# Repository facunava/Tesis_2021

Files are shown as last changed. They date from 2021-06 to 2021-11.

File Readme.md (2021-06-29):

# Tesis de grado. Grupo 6/2021
Este repositorio esta destinado al desarrollo de la tesis para obtener el grado de Ingeniero Electrónico en la Universidad Tecnológica Nacional Facultad regional de Córdoba.

---

## Problemática a resolver.
En la zona rural del Valle de Calamuchita (Córdoba, Argentina) se encuentra un emprendimiento cordobés "Azafrán Mediterráneo" dedicado a la cosecha, producción e inversión en "Crocus Sativus" (Azafrán), de esta planta violácea se utilizan los pistilos para la producción de la preciada especia, la cual se utiliza en una amplia variedad de rubros, ademas del azafrán de mesa, lo podemos encontrar como materia prima en linea estética para champú, perfumes, colonias, e incluso se utiliza en la producción de fernet.

<p align="center">
	Crocus Sativus 
</p>

Su alto valor comercial reside en la forma artesanal de su cosecha, de la misma manera que se hacia hace centenares de años, se sigue haciendo de forma manual, "Azafrán Mediterráneo" cuenta con "piletones" de material los cuales le permiten un mejor control de las variables que favorecen el crecimiento de los bulbos, como riego, fertilización y calidad del sustrato.

<p align="center">
	Piletones para cosecha 
</p>

Esta planta es azotada por una clase de hongo que crece en determinadas condiciones de temperatura y humedad, el objetivo de este proyecto es monitoriar dichas variables del suelo para poder activar unas electroválvulas del sistema de riego por goteo cambiando los valores que favorecen la proliferación del hongo.

Esto va a estar controlado a través de un servidor hosteado de forma local en una Raspberry Pi, en conjunto con una placa a modo de "HAT" que contenga un microcontrolador (ESP32) encargado de la adquisición de las lecturas de los sensores y activación de los actuadores.

---

## Integrantes

- Castro, Franco
- Cussa, Mayco
- Navarro, Facundo
- Nobile, Jonathan

---

### TODO
* Hardware
	+ Iniciar PCB

* Software
	+ Configurar Home Assistant
	+ Mejorar firmware ESP32

---

> Al fin y al cabo, somos lo que hacemos para cambiar lo que somos.
> - Eduadro Galeano.

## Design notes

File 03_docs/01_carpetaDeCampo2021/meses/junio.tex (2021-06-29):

\section{Junio 2021}

\subsection*{Martes 01/06/21}
    \begin{itemize}
        \item MQTT ESP32 y Raspberry Pi 3B+ en script "Python"
            \begin{itemize}
                 \item \href{https://www.instructables.com/How-to-Use-MQTT-With-the-Raspberry-Pi-and-ESP8266/}{Tutorial MQTT ESP8266 + Raspberry pi}
            \end{itemize}
\end{itemize}

\subsection*{Miércoles 02/06/21}
\begin{itemize}
    \item Prueba de servidor publico, web server nginx, DDNS publico de \href{https://www.noip.com/}{\textbf{No-IP}}, se abrieron los puertos del router 80 y se asigno una ip fija (192.168.1.100) a la RPi. 
    \begin{itemize}
        \item \href{http://facunava.ddns.net}{Pagina de prueba}
    \end{itemize}
    \item Se buscan materiales necesarios para calibración de sensores.
\end{itemize}    
\subsection*{Jueves 03/06/21}
    \begin{itemize}
        \item Prueba de framework Flask, en conjunto con el Web Server Nginx, y como herramienta de deployment Gunicorn, ya que por si solo flask sirve para ejecutar de forma local y no está orientado a usuarios multilples.
        \begin{itemize}
            \item \href{https://linuxhint.com/use-nginx-with-flask/}{Nginx + Flask + Gunicorn}
            \item \href{https://j2logo.com/tutorial-flask-leccion-17-desplegar-flask-produccion-nginx-gunicorn/}{Nginx + Flask + Gunicorn}
            \item \href{https://faun.pub/deploy-flask-app-with-nginx-using-gunicorn-7fda4f50066a}{Nginx + Flask + Gunicorn}
        \end{itemize}
        
        \item Prueba de comunicacion MQTT desde la ESP a la Rpi3 e intentamos presentar esa información a través de flask a una pagina web local en html.
        \begin{itemize}
            \item \href{https://www.rosietheredrobot.com/2018/11/red-current-and-serial.html}{MQTT + Esp32 + Http + WebSockets}
            \item \href{https://www.rosietheredrobot.com/2017/09/a-web-of-pies.html}{Instalación de Flask}
        \end{itemize}
    \end{itemize}
\subsection*{Viernes 04/06/21}
    \begin{itemize}
        \item Dia Libre.
    \end{itemize}

\subsection*{Sábado 05/06/21}
    \begin{itemize}
        \item Dia Libre.
    \end{itemize}

\subsection*{Domingo 06/06/21}
    \begin{itemize}
        \item Dia Libre.
    \end{itemize}
\subsection*{Lunes 07/06/21}
    \begin{itemize}
        \item Pruebas de servidores libres usando SQLite HTML HTTP 
        \item Se comienza el proceso de pruebas para la calibración de sensores.
        \begin{itemize}
            \item Se definen los volúmenes a ensayar.
            \item Se desarrolla un código de prueba.
            \item Se comprueba el funcionamiento de los sensores.
        \end{itemize}
    \end{itemize}
\subsection*{Martes 08/06/21}
    \begin{itemize}
        \item Envió de sensor de humedad/temperatura sht3x por parte de proveedor
        \item Pruebas de servidores, alternativas y variantes
    \end{itemize}

\subsection*{Miércoles 09/06/21}
    \begin{itemize}
        \item Cambio de enfoque prueba enviando datos (sensor de distancia HC-SR04) por MQTT desde ESP32 a raspberry y desde raspberry a servidor Thinkspeak.com (exitoso)
        \item Se consigue una balanza para realizar pruebas basadas en el método directo gravimétrico para mediciones de humedad de suelo.
    \end{itemize}
    
\subsection*{Jueves 10/06/21}
    \begin{itemize}
        \item Actualización de códigos en plataformas y organización de documentos.
    \end{itemize}
\subsection*{Viernes 11/06/21}
    \begin{itemize}
        \item Reunión nuevos avances y propuesta de primer visado para la fecha 2/7/21 
    \end{itemize}

\subsection*{Sábado 12/06/21}
    \begin{itemize}
        \item Día libre
    \end{itemize}

\subsection*{Domingo 13/06/21}
    \begin{itemize}
        \item Día libre 
    \end{itemize}
    
\subsection*{Lunes 14/06/21}
    \begin{itemize}
        \item Llega el producto "teclado matricial 4x4 de Membrana", Know how, Optimización de GPIO y adquisición de datos. 
        \item Se realizan mediciones de valores extremos del sensor para trazar la curva de respuesta.
        \begin{itemize}
            \item Se emplea balanza para pesar tierra para lecturas cercanas a 100\% de humedad.
            \item Se la seca en horno por 4 horas.
            \item Se deja enfriar por 2 horas.
            \item Se mide humedad para corroborar valores cercanos a 0\%.
            \item Se pesa nuevamente para ver el peso de agua evaporado.
        \end{itemize}
        
    \end{itemize}
    
\subsection*{Martes 15/06/21}
    \begin{itemize}
        \item Diseño 3D de soporte para teclado en gabinete.
    \end{itemize}
    
\subsection*{Miércoles 16/06/21}
    \begin{itemize}
        \item Se realizan nuevas mediciones para la calibración de sensores con el fin de eliminar errores en el proceso.
    \end{itemize}
    
\subsection*{Jueves 17/06/21}
    \begin{itemize}
        \item Se continua el proceso de calibración, incorporando el riego para observar valores intermedios en la escala de medición.
    \end{itemize}
    
\subsection*{Viernes 18/06/21}
    \begin{itemize}
        \item Llega pantalla de 7 pulgadas para display de gabinete.
    \end{itemize}
    
\subsection*{Sábado 19/06/21}
    \begin{itemize}
        \item Reunión para evaluar avances y verificar pendientes para primer visado. 
        \item Se comprueba correcto funcionamiento de la pantalla.
    \end{itemize}
    
\subsection*{Domingo 20/06/21}
    \begin{itemize}
        \item Día libre 
    \end{itemize}

\subsection*{Lunes 21/06/21}
    \begin{itemize}
        \item Primera aproximación de posible firmware final, con entorno de desarrollo InfluxDB, Telegraf y Grafena. 
        \begin{itemize}
            \item \href{http://pdacontroles.com/instalacion-completa-dashboard-grafana-en-raspberry-pi-3-b-b/}{Tutorial Grafana RPi 3B+.}
        \end{itemize}
    \end{itemize}
    
\subsection*{Martes 22/06/21}
    \begin{itemize}
        \item Prueba de botón en Grafana, para comunicación HTTP POST.
        \begin{itemize}
            \item \href{https://grafana.com/grafana/plugins/cloudspout-button-panel/}{Botón Grafana - Plugin Oficial.}
        \end{itemize}
    \end{itemize}
    
\subsection*{Miércoles 23/06/21}
    \begin{itemize}
        \item Montaje de servidor nodejs para recibir los comandos POST.
        \begin{itemize}
            \item \href{https://www.npmjs.com/package/server}{Servidor nodejs.}
        \end{itemize}
        \item Problema de comunicación por seguridad CORS (Intercambio de Recursos de Origen Cruzado).
        \begin{itemize}
            \item \href{https://developer.mozilla.org/es/docs/Web/HTTP/CORS}{CORS Mozila.}
        \end{itemize}
    \end{itemize}
    
\subsection*{Jueves 24/06/21}
    \begin{itemize}
        \item Analisis y estudio de migrar el sistema a Home Assistant.
        \begin{itemize}
            \item \href{https://www.home-assistant.io/installation/raspberrypi}{Instalación Home Assistant Raspberry Pi.}
        \end{itemize}
    \end{itemize}
 
\subsection*{Viernes 25/06/21}
    \begin{itemize}
        \item Instalación de Home Assistant Core. Se probó la instalación en Docker pero el arranca demoraba, 5 minutos aproximadamente. 
        \begin{itemize}
            \item \href{https://www.home-assistant.io/installation/raspberrypi}{Instalación Home Assistant Raspberry Pi.}
        \end{itemize}
        \item Instalación de herramientas gráficas y chrome para inicializar Home Assistant desde el browser.
        \begin{itemize}
            \item \href{https://sylvaindurand.org/launch-chromium-in-kiosk-mode/}{Modo kiosko en Chrome.}
            \item \href{https://die-antwort.eu/techblog/2017-12-setup-raspberry-pi-for-kiosk-mode/}{RPi Web Browser en modo Kiosko.}
        \end{itemize}
    \end{itemize}    

\subsection*{Sabado 26/06/21}
    \begin{itemize}
        \item Reunión para integrar teclado con el resto del sistema. Programación de teclado para que capte eventos y se comporte como un teclado real.
        \begin{itemize}
            \item \href{https://github.com/nutki/rpi-gpio-matrix-keyboard}{Raspberry Pi GPIO Matrix Keyboard.}
            \item \href{https://softsolder.com/2016/03/02/raspberry-pi-usb-keypad-via-evdev/}{Raspberry Pi: USB Keypad Via evdev.}
        \end{itemize}
    \end{itemize}

\subsection*{Domingo 27/06/21}
    \begin{itemize}
        \item Día libre 
    \end{itemize}

\subsection*{Lunes 28/06/21}
\subsection*{Martes 29/06/21}
\subsection*{Miércoles 30/06/21}

\clearpage

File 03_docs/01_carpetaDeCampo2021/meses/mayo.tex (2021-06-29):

\section{Mayo 2021}

\subsection*{Lunes 24/05/21}
    \begin{itemize}
        \item Reunion para ver estrategias Agiles, Scrum.
    \end{itemize}

\subsection*{Martes 25/05/21}
    \begin{itemize}
        \item Prueba Micropython en ESP32. \textcolor{red}{Descartado}, falta de soporte. Pudimos cargar los ejemplos de los programas basicis (blinky, leer puerto serie, i2c scan), pero vemos que hay pocas librerias desarrolladas para upython y upip.
            \begin{itemize}
                \item \href{https://micropython.org/download/}{uPython.}
                \item \href{http://docs.micropython.org/en/v1.15/esp32/tutorial/intro.html}{Tutorial uPython en ESP32.}
                \item \href{http://docs.micropython.org/en/v1.15/esp8266/tutorial/index.html#esp8266-tutorial}{Tutorial uPython en ESP8266.}
            \end{itemize}
        \item Se investiga sobre sensores usados en la industria
            \begin{itemize}
                \item Algunos de los mas usados son los de 'Meter Enviroment'
                \item Los modelos de la línea TEROS y ECH20 serían los mas adecuados para nuestra aplicación.
                \item Su costo va desde los U\$D 80 a U\$D 200.
            \end{itemize}
    \end{itemize}

\subsection*{Miércoles 26/05/21}
\begin{itemize}
    \item Prueba Libreria de sensor SHT (SHT-Esp32) en Heltec Lora ESP32 v2, \textcolor{red}{no funciona} en esta placa.
    \item Prueba Libreria de sensor SHT (SHT-Esp32) en placa Arduino Uno, \textcolor{ForestGreen}{funciona correctamente}.
        \begin{itemize}
            \item \href{https://github.com/beegee-tokyo/SHT1x-ESP}{Libreria SHT1x-ESP}
        \end{itemize}
    \item Prueba MQTT entre Heltec Lora-ESP32 y Raspberry pi 3b+ (funciona)
    \item Se busca información en general sobre mediciones de humedad, protocolos de calibración y tipos de sensores. Se encuentran dos documentos que describen los pasos correctos para la instalación de sensores y señalan diversos métodos de calibración.
        \begin{itemize}
            \item \href{https://www.metergroup.com/environment/events/soil-moisture-201-measurements-methods-and-applications/}{Webinario: Soil Moisture 201: Water Content Measurements, Methods, and Applications}
        \end{itemize}
    
\end{itemize}

\subsection*{Jueves 27/05/21}
\begin{itemize}
    \item Prueba Libreria de sensor SHT (SHT-Esp32) en NodeMCUv1 basado en ESP8266, \textcolor{ForestGreen}{funciona correctamente}.
        \begin{itemize}
            \item \href{https://github.com/beegee-tokyo/SHT1x-ESP}{Libreria SHT1x-ESP}
        \end{itemize}
    \item Prueba MQTT entre Heltec Lora-ESP32 y Raspberry pi 3b+ con envió de datos, fallas en puerto de com 1883 
    \item Se buscan fórmulas que nos permitan comprobar el correcto funcionamiento del sensor. Se encuentran muchas formas de medir la humedad, por lo que vamos a tener que probarlas respecto de nuestro sensor para ver cuál se adapta mejor.
    \item Se encuentra un seminario sobre mediciones de humedad en suelo.
    
\end{itemize}
\subsection*{Viernes 28/05/21}
\begin{itemize}
    \item Determinación de sensor SHT30 compra para actualizar el SHT11
    \item \textcolor{orange}{Compra 2 Sensores SHT30, MUX I2C TCA9548a}
\end{itemize}
\subsection*{Sábado 29/05/21 y Domingo 30/05/21}
    \begin{itemize}
        \item Día Libre.
    \end{itemize}

\subsection*{Lunes 31/05/21}
    \begin{itemize}
        \item Reunión para organizar la semana, hasta que vengan los sensores vamos a avanzar en el web server y en los procedimientos de calibración para los sensores.
        \item Prueba de MQTT + ESP32 (\textcolor{ForestGreen}{Andando!})
        \begin{itemize}
            \item \href{https://randomnerdtutorials.com/esp8266-and-node-red-with-mqtt/}{ESP8266, node-red, MQTT}
            \item \href{https://randomnerdtutorials.com/getting-started-with-node-red-on-raspberry-pi/}{Node-RED y RPi}
            \item \href{https://programarfacil.com/esp8266/mqtt-esp8266-raspberry-pi/}{MQTT, ESP8266, RPi}
        \end{itemize}
    \end{itemize}

\clearpage

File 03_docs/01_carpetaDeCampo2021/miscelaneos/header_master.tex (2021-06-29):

\usepackage[utf8]{inputenc}
\usepackage[spanish]{babel}
\usepackage[linktoc=all]{hyperref}

\usepackage{graphicx}
\usepackage{caption}
\usepackage{float}

\usepackage[dvipsnames]{xcolor}

\usepackage{import} %reemplaza a input incluyendo el path relativo al archivo importado
\usepackage{soul}   %otros formatos de texto, \st{%text%} tachado
%------------------- Dimensiones -------------------
\usepackage{geometry}
\geometry{a4paper, total={170mm, 240mm}, top=20mm, left=20mm}
\setlength{\headheight}{15mm}% ...at least 51.60004pt
\setlength{\footskip}{15mm}% ...at least 51.60004pt
%----------------------------------------------------

%------------------- Encabezado y Pie de pág -------------------
\usepackage{fancyhdr}
\pagestyle{fancy}
\fancyhf{}
\lhead{Cátedra de Proyecto Final}
\rhead{Carpeta de campo}
\rfoot{Página \thepage}
%----------------------------------------------------

\usepackage{gensymb} %Para poder poner el ° usando \degree

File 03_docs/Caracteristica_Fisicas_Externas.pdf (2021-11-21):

Característica Físicas Externas
Caja Pase estanca IP65 | Material: PVC
Color | Gris
Dimensiones | 305x305x170mm
Peso | 2215g
Tapa transparente | Material: Acrílico
Torre lumínica de 3 lámparas con soporte | Material: PVC y Aluminio
Característica Físicas Internas
Caja Pase estanca IP65 | Material: PVC
Color | Blanca
Dimensiones | 115x115x110mm
Base de PCB | Material: PLA
Prensa cable varios | PVC nylon
Característica Principales PCB
Microcontrolador | ESP-WROOM-32
Microprocesador | Xtensa Dual-Core 32-bit LX6
Banda de Frecuencia Wi-Fi (802.11 b/g/n) | 2.4 Ghz
Protocolo de Comunicación | MQTT
Tensión de alimentación | 3,3v
Frecuencia de Operación | 160Mhz
Dimensiones | 150x100x2mm
Características Principales Raspberry Pi
Procesador | Broadcom BCM2711 (ARM8)
Memoria RAM | 8GB LPDDR4
Conectividad: LAN inalámbrica IEEE 802.11b | 2.4 GHz y 5.0 GHz
Gigabit Ethernet | -
Alimentación | 5v
Dimensiones | 88x58x1.85mm
Solenoide
Circuito Integrado | MOC3041
Corriente de mantenimiento | 0,105mA
Control mediante | I2C
Conexionado | PCF8574
Tensión de alimentación | 24Vac
Alertas Lumínicas - 3 Lámparas
Circuito Integrado | 3041
Corriente | 208mA
Tensión de alimentación | 24Vac
Alerta Sonora
Mosfet N-channel | bss138
Consumo | 30mA
tensión de alimentación | 5v
Fuente de Alimentación General
Tensión | 24VAC / 1,5A
Rectificador | 33v
Sensores de Humedad y Temperatura
Rango de Alimentación | 2,4 - 5v
Protocolo de Comunicación | I2C
Tolerancia de Precisión | ± 2% Resolución Humidity
| ± 0.3 °C Temperatura
Conexionado | TC9548
GPS GY-NEO6MV2
Alimentación | 5v
Microcontrolador | AVR ARM PIC
RTC
Alimentación | 5v
Microcontrolador | DS3231

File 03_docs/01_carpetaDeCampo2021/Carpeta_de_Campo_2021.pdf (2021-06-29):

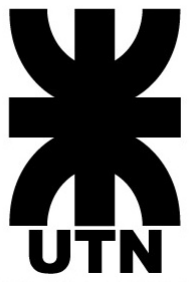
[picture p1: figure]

Universidad Tecnologica Nacional ´

Facultad Regional de Cordoba ´

## Cátedra de Proyecto Final

## Tesis de Grado

## “Carpeta de campo.”

Castro, Franco | 67432
Cussa, Mayco | 66871
Navarro, Facundo | 63809
Nobile, Jonathan | 69325

Docentes:
Ing. Encina, Lucas
Ing. Galleguillo, Juan Cayetano del Corazón Ing. Gaydou, David

29 de junio de 2021

Cátedra de Proyecto Final | Carpeta de campo

## Índice

1. Mayo 2021 | 2
2. Junio 2021 | 4
3. Julio 2021 | 8
4. Protocolo de calibración | 8
5. Enlaces de interés. | 16

Página 1

## 1. Mayo 2021

Lunes 24/05/21

Reunion para ver estrategias Agiles, Scrum.

Martes 25/05/21

Prueba Micropython en ESP32. Descartado, falta de soporte. Pudimos cargar los ejemplos de los programas basicis (blinky, leer puerto serie, i2c scan), pero vemos que hay pocas librerias desarrolladas para upython y upip.

- uPython. (https://micropython.org/download/)
- Tutorial uPython en ESP32. (http://docs.micropython.org/en/v1.15/esp32/tutorial/intro.html)
- Tutorial uPython en ESP8266. (http://docs.micropython.org/en/v1.15/esp8266/tutorial/index.html#esp8266-tutorial)

Se investiga sobre sensores usados en la industria

- Algunos de los mas usados son los de ’Meter Enviroment’
- Los modelos de la línea TEROS y ECH20 serían los mas adecuados para nuestra aplicación.
- Su costo va desde los U$D 80 a U$D 200.

Miércoles 26/05/21

Prueba Libreria de sensor SHT (SHT-Esp32) en Heltec Lora ESP32 v2, no funciona en esta placa.

Prueba Libreria de sensor SHT (SHT-Esp32) en placa Arduino Uno, funciona correctamente.

- Libreria SHT1x-ESP (https://github.com/beegee-tokyo/SHT1x-ESP)

Prueba MQTT entre Heltec Lora-ESP32 y Raspberry pi 3b+ (funciona)

Se busca información en general sobre mediciones de humedad, protocolos de calibración y tipos de sensores. Se encuentran dos documentos que describen los pasos correctos para la instalación de sensores y señalan diversos métodos de calibración.

- Webinario: Soil Moisture 201: Water Content Measurements, Methods, and Applications (https://www.metergroup.com/environment/events/soil-moisture-201-measurements-methods-and-applications/)

Jueves 27/05/21

Prueba Libreria de sensor SHT (SHT-Esp32) en NodeMCUv1 basado en ESP8266, funciona correctamente.

- Libreria SHT1x-ESP (https://github.com/beegee-tokyo/SHT1x-ESP)

Prueba MQTT entre Heltec Lora-ESP32 y Raspberry pi 3b+ con envió de datos, fallas en puerto de com 1883

Se buscan fórmulas que nos permitan comprobar el correcto funcionamiento del sensor. Se encuentran muchas formas de medir la humedad, por lo que vamos a tener que probarlas respecto de nuestro sensor para ver cuál se adapta mejor.

Se encuentra un seminario sobre mediciones de humedad en suelo.

Viernes 28/05/21

Determinación de sensor SHT30 compra para actualizar el SHT11

Compra 2 Sensores SHT30, MUX I2C TCA9548a

Sábado 29/05/21 y Domingo 30/05/21

Día Libre.

Lunes 31/05/21

Reunión para organizar la semana, hasta que vengan los sensores vamos a avanzar en el web server y en los procedimientos de calibración para los sensores.

Prueba de MQTT + ESP32 (Andando!)

- ESP8266, node-red, MQTT (https://randomnerdtutorials.com/esp8266-and-node-red-with-mqtt/)
- Node-RED y RPi (https://randomnerdtutorials.com/getting-started-with-node-red-on-raspberry-pi/)
- MQTT, ESP8266, RPi (https://programarfacil.com/esp8266/mqtt-esp8266-raspberry-pi/)

## 2. Junio 2021

Martes 01/06/21

MQTT ESP32 y Raspberry Pi 3B+ en script ”Python”

- Tutorial MQTT ESP8266 + Raspberry pi (https://www.instructables.com/How-to-Use-MQTT-With-the-Raspberry-Pi-and-ESP8266/)

Miércoles 02/06/21

Prueba de servidor publico, web server nginx, DDNS publico de No-IP, (https://www.noip.com/) se abrieron los puertos del router 80 y se asigno una ip fija (192.168.1.100) a la RPi.

- Pagina de prueba (http://facunava.ddns.net)

Se buscan materiales necesarios para calibración de sensores.

Jueves 03/06/21

Prueba de framework Flask, en conjunto con el Web Server Nginx, y como herramienta de deployment Gunicorn, ya que por si solo flask sirve para ejecutar de forma local y no está orientado a usuarios multilples.

- Nginx + Flask + Gunicorn (https://linuxhint.com/use-nginx-with-flask/)
- Nginx + Flask + Gunicorn (https://j2logo.com/tutorial-flask-leccion-17-desplegar-flask-produccion-nginx-gunicorn/)
- Nginx + Flask + Gunicorn (https://faun.pub/deploy-flask-app-with-nginx-using-gunicorn-7fda4f50066a)

Prueba de comunicacion MQTT desde la ESP a la Rpi3 e intentamos presentar esa información a través de flask a una pagina web local en html.

- MQTT + Esp32 + Http + WebSockets (https://www.rosietheredrobot.com/2018/11/red-current-and-serial.html)
- Instalación de Flask (https://www.rosietheredrobot.com/2017/09/a-web-of-pies.html)

Viernes 04/06/21

Dia Libre.

Sábado 05/06/21

Dia Libre.

Domingo 06/06/21

Dia Libre.

Lunes 07/06/21

Pruebas de servidores libres usando SQLite HTML HTTP

Se comienza el proceso de pruebas para la calibración de sensores.

- Se definen los volúmenes a ensayar.
- Se desarrolla un código de prueba.
- Se comprueba el funcionamiento de los sensores.

Martes 08/06/21

Envió de sensor de humedad/temperatura sht3x por parte de proveedor

Pruebas de servidores, alternativas y variantes

Miércoles 09/06/21

Cambio de enfoque prueba enviando datos (sensor de distancia HC-SR04) por MQTT desde ESP32 a raspberry y desde raspberry a servidor Thinkspeak.com (exitoso)

Se consigue una balanza para realizar pruebas basadas en el método directo gravimétrico para mediciones de humedad de suelo.

Jueves 10/06/21

Actualización de códigos en plataformas y organización de documentos.

Viernes 11/06/21

Reunión nuevos avances y propuesta de primer visado para la fecha 2/7/21

Sábado 12/06/21

Día libre

Domingo 13/06/21

Día libre

Lunes 14/06/21

Llega el producto ”teclado matricial 4x4 de Membrana”, Know how, Optimización de GPIO y adquisición de datos.

Se realizan mediciones de valores extremos del sensor para trazar la curva de respuesta.

- Se emplea balanza para pesar tierra para lecturas cercanas a 100 % de humedad.
- Se la seca en horno por 4 horas.
- Se deja enfriar por 2 horas.
- Se mide humedad para corroborar valores cercanos a 0 %.
- Se pesa nuevamente para ver el peso de agua evaporado.

Martes 15/06/21

Diseño 3D de soporte para teclado en gabinete.

Miércoles 16/06/21

Se realizan nuevas mediciones para la calibración de sensores con el fin de eliminar errores en el proceso.

Jueves 17/06/21

Se continua el proceso de calibración, incorporando el riego para observar valores intermedios en la escala de medición.

Viernes 18/06/21

Llega pantalla de 7 pulgadas para display de gabinete.

Sábado 19/06/21

Reunión para evaluar avances y verificar pendientes para primer visado.

Se comprueba correcto funcionamiento de la pantalla.

Domingo 20/06/21

Día libre

Lunes 21/06/21

Primera aproximación de posible firmware final, con entorno de desarrollo InfluxDB, Telegraf y Grafena.

- Tutorial Grafana RPi 3B+. (http://pdacontroles.com/instalacion-completa-dashboard-grafana-en-raspberry-pi-3-b-b/)

Martes 22/06/21

Prueba de botón en Grafana, para comunicación HTTP POST.

- Botón Grafana - Plugin Oficial. (https://grafana.com/grafana/plugins/cloudspout-button-panel/)

Miércoles 23/06/21

Montaje de servidor nodejs para recibir los comandos POST.

- Servidor nodejs. (https://www.npmjs.com/package/server)

Problema de comunicación por seguridad CORS (Intercambio de Recursos de Origen Cruzado).

- CORS Mozila. (https://developer.mozilla.org/es/docs/Web/HTTP/CORS)

Jueves 24/06/21

Analisis y estudio de migrar el sistema a Home Assistant.

- Instalación Home Assistant Raspberry Pi. (https://www.home-assistant.io/installation/raspberrypi)

Viernes 25/06/21

Instalación de Home Assistant Core. Se probó la instalación en Docker pero el arranca demoraba, 5 minutos aproximadamente.

- Instalación Home Assistant Raspberry Pi. (https://www.home-assistant.io/installation/raspberrypi)

Instalación de herramientas gráficas y chrome para inicializar Home Assistant desde el browser.

- Modo kiosko en Chrome. (https://sylvaindurand.org/launch-chromium-in-kiosk-mode/)
- RPi Web Browser en modo Kiosko. (https://die-antwort.eu/techblog/2017-12-setup-raspberry-pi-for-kiosk-mode/)

Sabado 26/06/21

Reunión para integrar teclado con el resto del sistema. Programación de teclado para que capte eventos y se comporte como un teclado real.

- Raspberry Pi GPIO Matrix Keyboard. (https://github.com/nutki/rpi-gpio-matrix-keyboard)
- Raspberry Pi: USB Keypad Via evdev. (https://softsolder.com/2016/03/02/raspberry-pi-usb-keypad-via-evdev/)

Domingo 27/06/21

Día libre

Lunes 28/06/21

Martes 29/06/21

Miércoles 30/06/21

## 3. Julio 2021

Jueves 01/07/21

Viernes 02/07/21

## 4. Protocolo de calibración

En esta sección daremos un paso a paso del proceso a seguir para poder comprobar la correcta calibración de un sensor de humedad de suelo.

### 4.1. Elementos necesarios

Para realizar la calibración necesitaremos:

Recipiente graduado o de volumen conocido: Debe ser lo suficientemente grande para almacenar la muestra de tierra deseada con el nivel de compactación y densidad requerida, teniendo espacio también para el sensor. También se recomienda que el recipiente sea relativamente rígido y permita un fácil acceso a la superficie del suelo a medir. Es muy importante poder saber el volumen del recipiente, ya que esto nos permite calcular el contenido volumétrico de agua.

Recipientes para secado en horno.

Tierra de características conocidas: Se recomienda no usar tierra con mucha composición orgánica, ya que la misma suele volatilizarse al hornearla, generando grandes errores de medición.

Sensor de humedad a verificar: El proceso a realizar es válido para todos los sensores de tipo capacitivo, por lo que la calibración puede aplicarse a otros sensores que se usen en el mismo tipo de suelo.

Balanza: Se necesita que tenga capacidad para pesar hasta 5 kilos y una resolución de al menos 1 gramo.

Balanza de precisión: Se necesita que tenga una resolución de al menos 0.1 gramo.

Horno o dispositivo para secar la muestra: Cualquier horno capaz de mantener 105 o 110 ◦C sirve.

Pulverizador a gatillo: Se empleará para una distribución uniforme de agua sobre la muestra.

Sistema de adquisición de datos.

Tutor para insertar sensor: Un dispositivo con punta, de diámetro similar al sensor, que se usará para clavar en la tierra y hacer espacio para la posterior instalación.

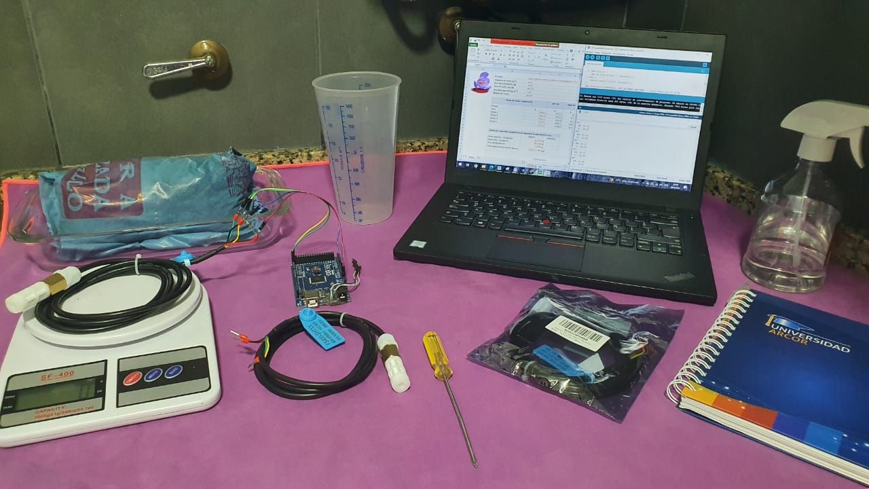
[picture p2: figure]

Figura 1: Materiales utilizados.

### 4.2. Procedimiento

### 4.2.1. Preparación de la muestra

1. Pesar el recipiente (limpio y seco) donde se almacenará la muestra.
2. Debemos obtener la muestra a sensar. Para ello tenemos dos opciones, siendo la primera tomarla directamente del suelo a analizar, empleando un recipiente/sacabocados de volumen conocido; o bien colocando la tierra de propiedades conocidas en un recipiente y compactándola hasta alcanzar la densidad requerida.
3. Tomar una sub muestra de 10 gramos usando una cuchara o herramienta similar y colocarlo en un recipiente para secado.
4. Pesar la sub muestra + recipiente (de peso conocido) Mwet+recipB
y taparla para evitar la perdida de humedad. Guardarla para su posterior secado.
5. Anotar el peso (Mwet) y volumen (Vsoil) de la muestra principal.
6. Remover objetos grandes que puedan alterar las mediciones, como ser piedras, siempre y cuando no alteren la naturaleza de la muestra.
7. En caso de ser suelos muy arcillosos o finos, tomar una medición de la altura que ocupa dentro del recipiente, ya que posteriormente su volumen puede cambiar al agregarle agua, por lo que sabiendo la altura se puede llegar a calcular una corrección.

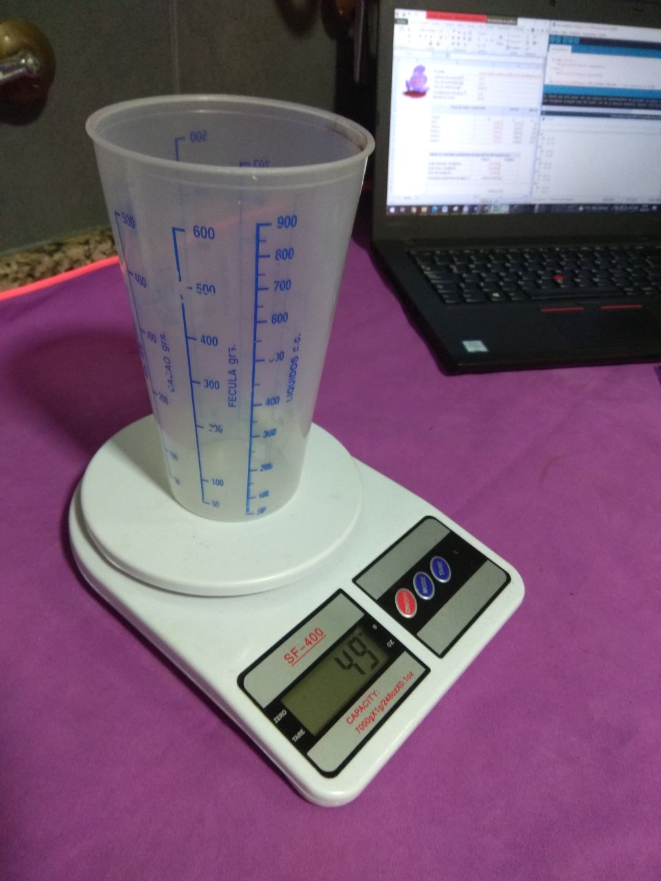
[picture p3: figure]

Figura 2: Pesaje del recipiente.

### 4.2.2. Secado

1. Hornear la muestra principal a 110◦C hasta lograr que esté completamente seca, variando el tiempo según el peso de muestra. Es recomendable esparcir la tierra en finas capas sobre una bandeja para lograr un secado mas rápido y uniforme.
2. Sacar del horno y dejar enfriar por 2 horas.
3. Pesar el suelo seco para obtener Mdry.
4. Calcular la densidad aparente del suelo con la ecuación 6.

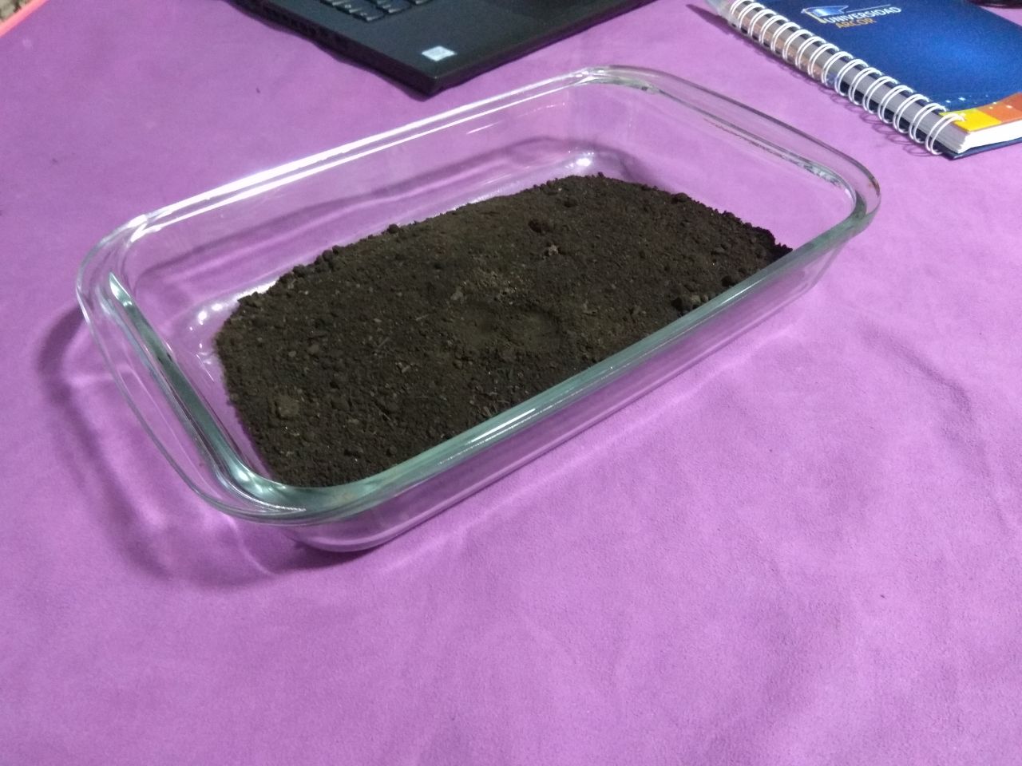
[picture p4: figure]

Figura 3: Secado de tierra en horno.

### 4.2.3. Calibración

1. Colocar la tierra seca en el contenedor para calibración, respetando la densidad y compactación necesaria. Para esto se recomienda ir depositando de a finas capas y compactándolas poco a poco.
2. Introducir el sensor en la muestra, teniendo mucho cuidado de que no queden holguras con aire. Es muy importante que tenga un contacto pleno con la muestra para obtener mediciones acertadas. Se recomienda usar un tutor para hacer el hueco donde tiene que entrar el sensor. Este tiene que quedar completamente dentro de la tierra. Evitar colocarlo en un agujero usado por otro sensor anteriormente.
3. Conectar el sensor al dispositivo de adquisición y anotar los valores RAW obtenidos.
4. Retirar el sensor.
5. Regar la tierra siguiendo una proporción de 1ml de agua por cada 10 ml de tierra, lo que aumentará en un 10 % el contenido de agua volumétrico (VW C). Regar lo mas pareja posible la superficie.
6. Cuidadosamente mezclar la tierra con una cuchara o herramienta similar hasta lograr una con-sistencia y humedad homogénea.
7. Repetir los pasos de 2 a 6 hasta lograr la saturación de la tierra, proceso que puede llevar entre 4 y 6 lecturas, con una demora en la adquisición de una hora para cada una.
8. Es importante destacar que la densidad y compactación de suelo debe mantenerse a lo largo de la prueba, logrando esto asegurándonos de que el volumen de la muestra se mantenga constante sin importar el contenido de agua agregada.

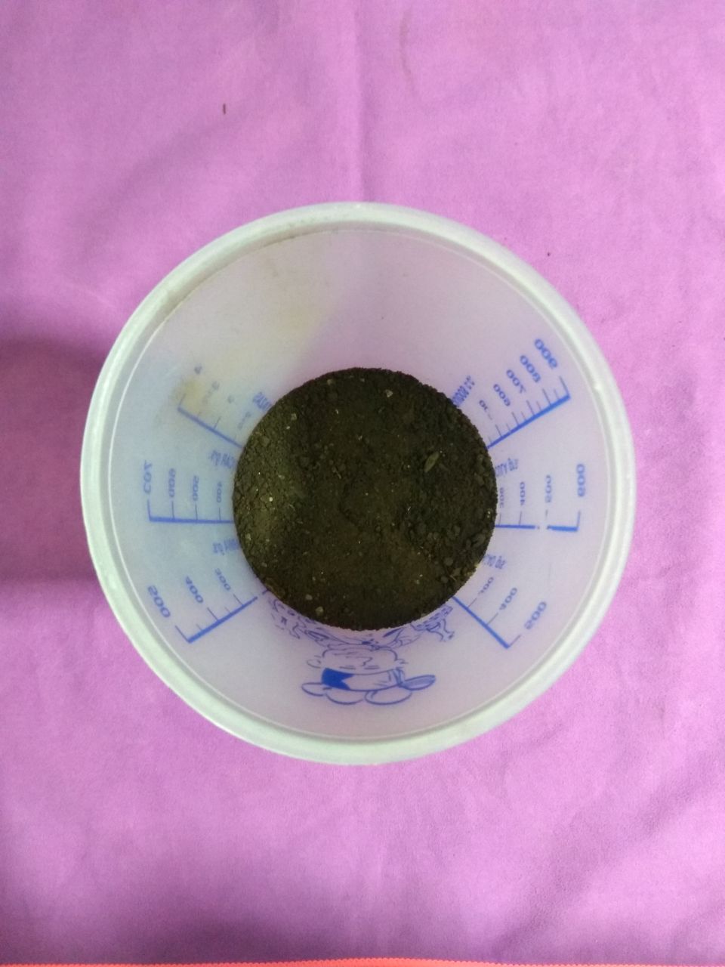
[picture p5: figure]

Figura 4: Recipiente con tierra a medir.

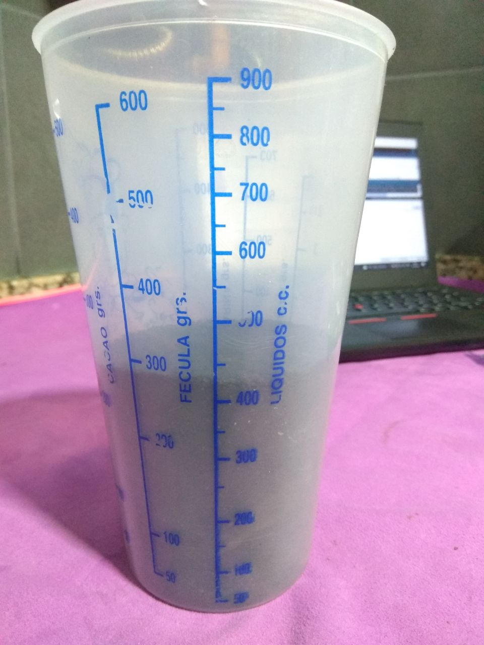
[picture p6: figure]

Figura 5: Volumen de tierra a medir.

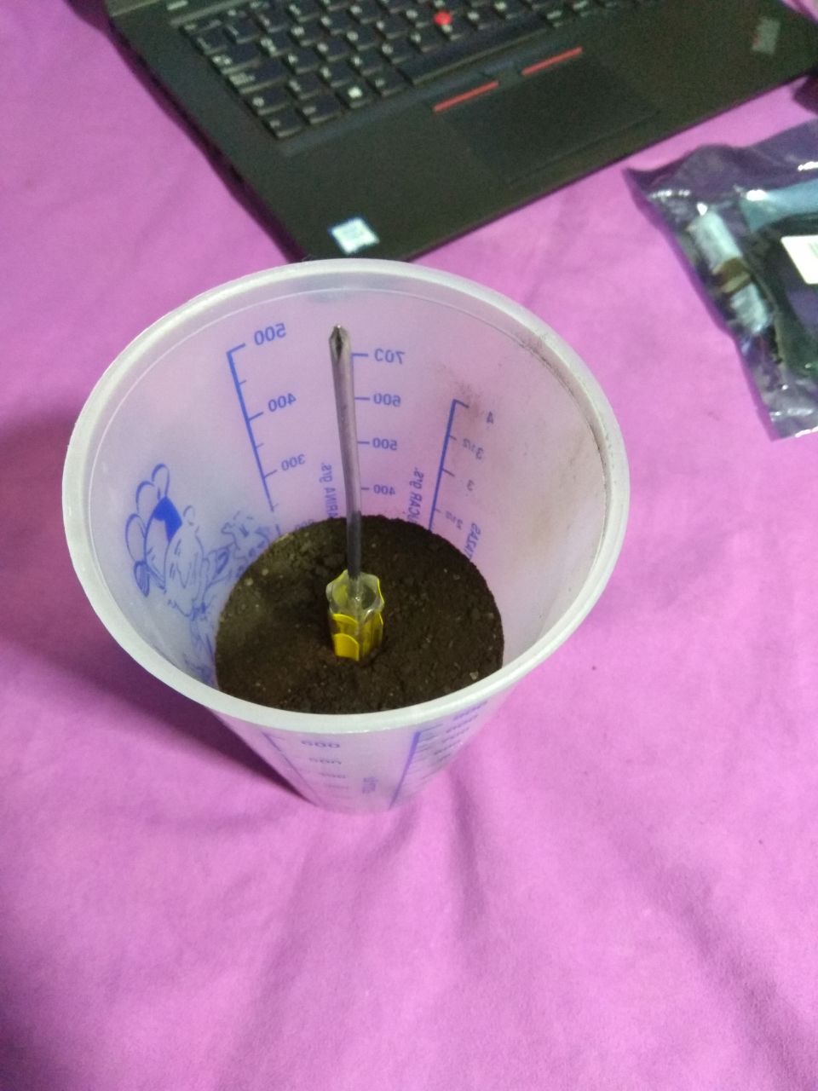
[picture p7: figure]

Figura 6: Tutor para preparación de suelo.

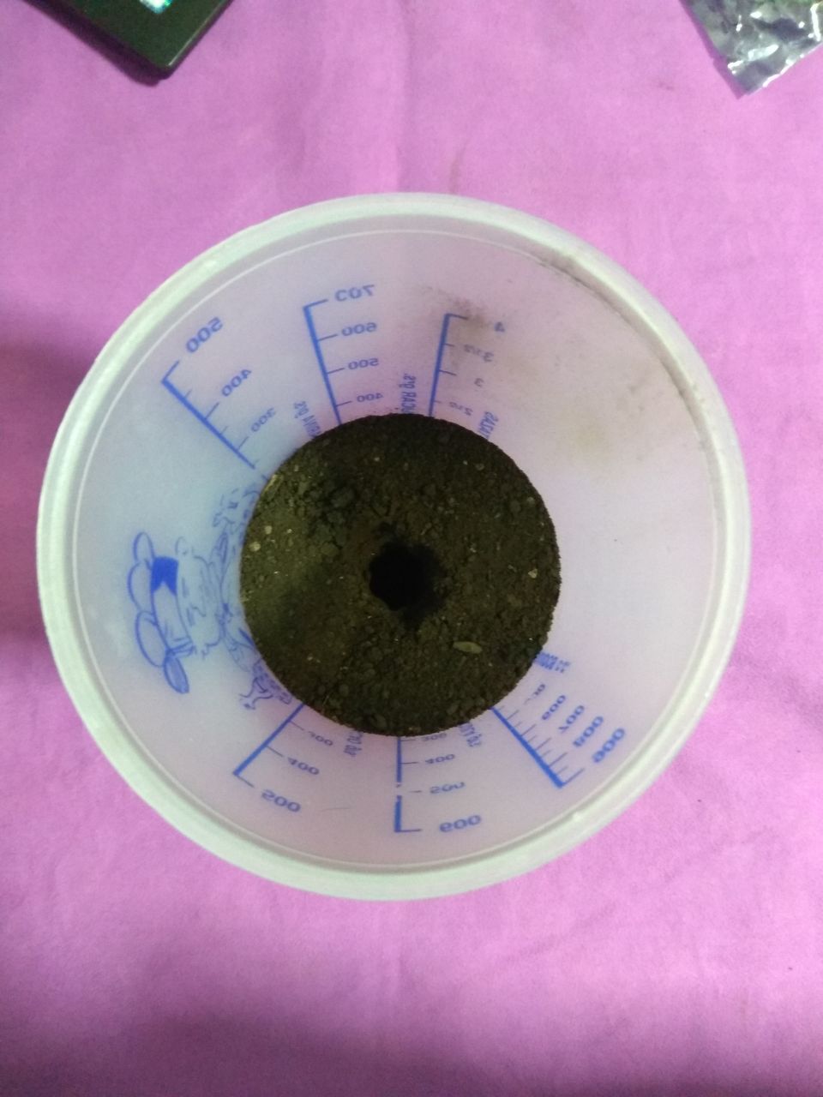
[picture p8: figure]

Figura 7: Hueco para la inserción del sensor.

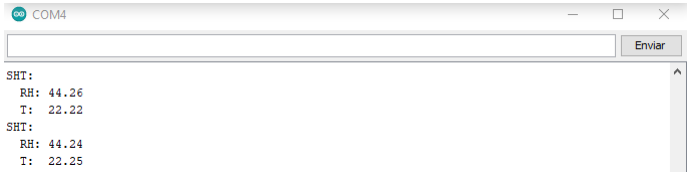
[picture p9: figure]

Figura 8: Captura de algunas mediciones tomadas.

### 4.2.4. Sub-muestra

1. Secar la sub-muestra de 10 gramos obtenida al principio, colocándola en el horno a 105 ◦C por 24 horas, duplicándose ese tiempo si se trata de tierra con alto componente orgánico, siendo necesario en esos casos usar una temperatura de 65 ◦C.
2. Sacar del horno y dejar enfriar por 2 horas.
3. Pesar el suelo seco para obtener Mdry+recipB

### 4.2.5. Cálculo y resultados

1. Todas las mediciones obtenidas, sean de peso, volumen o humedad y colocarlas en la tabla de excel para tal fin.
2. Interpretar el gráfico de la recta de respuesta del sensor y compararlo con el del datasheet para verificar la correlación.

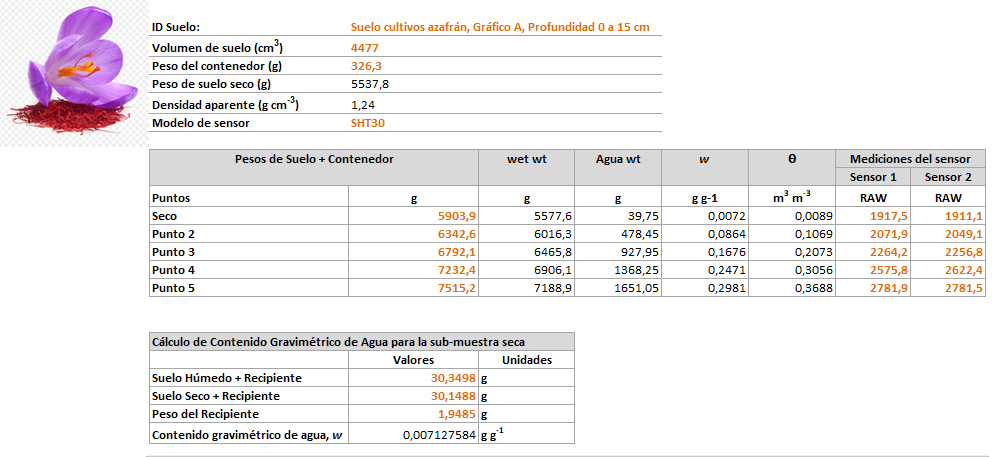
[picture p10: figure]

Figura 9: Planilla de excel usada para cálculos.

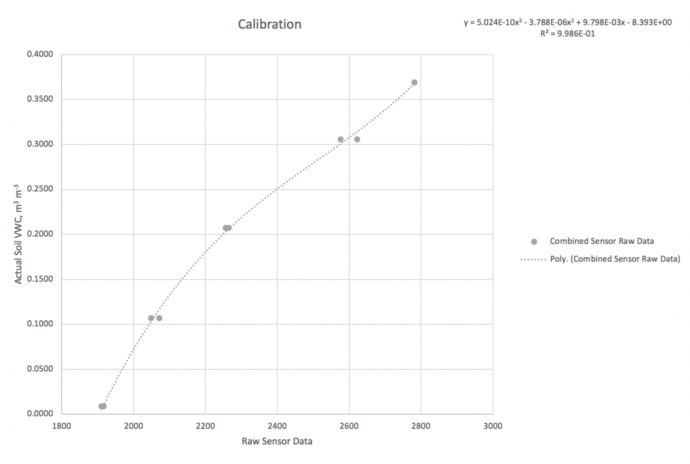
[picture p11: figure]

Figura 10: Curva de respuesta del sensor.

### 4.3. Cálculos

El contenido volumétrico del agua se define como el volumen de agua por volumen de suelo, donde θ representa el contenido volumétrico de agua, medido en cm³
cm³ .
Otros conceptos que usaremos en este proceso son el volumen de agua, representado con VW y medido en cm³
, y volumen total, que en este caso hace referencia a la capacidad total del contenedor usado para tomar la muestra, representado por VT y medido en cm³

θ =

Vw
Vt

(1)

Para calcular el volumen de agua, primero es necesario encontrar la cantidad inicial de agua en nuestra muestra, que se calcula restando el peso total del agua de la muestra, obtenida al multiplicar el peso de la muestra secada por el contenido gravimétrico de agua que se encontró a partir de la sub-muestra de la sección 3.2.4.

msoil,sample = msoil,sub−sample − (msoil,sub−sample · w) | (2)

Donde msoil,sub−sample es la masa de suelo con la que comenzamos y w el contenido gravimétrico de agua calculado a partir de la sub-muestra.

w =

msoil,sub−sample − msoil,sample

msoil,sample

(3)

Luego, para encontrar Vw para cada punto de calibración, hay que restar el peso del contenedor y el de msoil,sample del peso total de la muestra.

mw = mtotal − msoil,sample | (4)

Vw =

mw
ρw

(5)

Dónde mw es la masa de agua, mtotal es la masa de suelo húmedo medida en gramos, msoil,sample es la masa de la muestra secada en horno y ρ es la densidad de agua considerada como 1gr
cm³ .
Si usamos Vt
, podemos calcular el contenido volumétrico de agua y la densidad aparente del suelo mediante la ecuación 1, estando esta última definida como la densidad de suelo seco, representada como ρb y medida en g
cm³ .

ρb =

mdry

Vsoil

(6)

Todo lo anterior, en conjunto con la tabla de excel que se encuentra adjunta, permiten realizar la verificación de calibración de nuestro sensor, siendo esto apreciable en el gráfico presente en esta última, el cual usa la herramienta de tendencia para interconectar las mediciones obtenidas y obtener la respuesta de nuestro sensor, la cual puede ser lineal, variando en casos donde la tierra presente un alto contenido de materia orgánica.

5. Enlaces de interés.

“Azafrán Mediterráneo” página principal (http://www.azafranmediterraneo.com.ar/#/inicio)

”Meter Enviroment” página principal (https://www.metergroup.com/environment/)

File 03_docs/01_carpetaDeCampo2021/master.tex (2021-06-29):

%\import {〈full-path〉} {〈file〉} and
%\subimport {〈path-extension〉} {〈file〉}

\documentclass[11pt, oneside]{article}
\input{miscelaneos/header_master}

\begin{document}
\input{miscelaneos/cover}

%---------------------- INICIO INDICE ----------------------
\tableofcontents
\clearpage
%---------------------- FIN INDICE ----------------------
\subimport{meses}{mayo}
\subimport{meses}{junio}
\subimport{meses}{julio}
\subimport{meses}{calibracion}

%% Enlaces
\section{Enlaces de interés.}
    \subimport{links}{links}

\end{document}

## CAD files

01_hardware/v0/imports/rpi_MECH_3bplus.dxf
11
5
1
N
K
E
A
13
R 007-AG0046
CMIIT ID: 2018AJ2147
KCC: R-CMM-P2R-RPI3P
IFETEL: RCPRARA18-1020
IN CHINA
PCB MADE
PEN
IC: 20953-RPI3P
FCC ID: 2ABCB-RPI3BP
Licensed from
Proant AB
Uses technology
PoE
c Raspberry Pi 2017
Raspberry Pi 3 Model B
MICRO SD CARD
HDMI
BOTOM LEGEND
BOTTOM ASSEMBLY
TOP LEGEND
TOP ASSEMBLY
Made in the UK
A/V
GPIO
USB
ETHERNET
PWR IN
DISPLAY
CAMERA
RUN
ACT
PWR

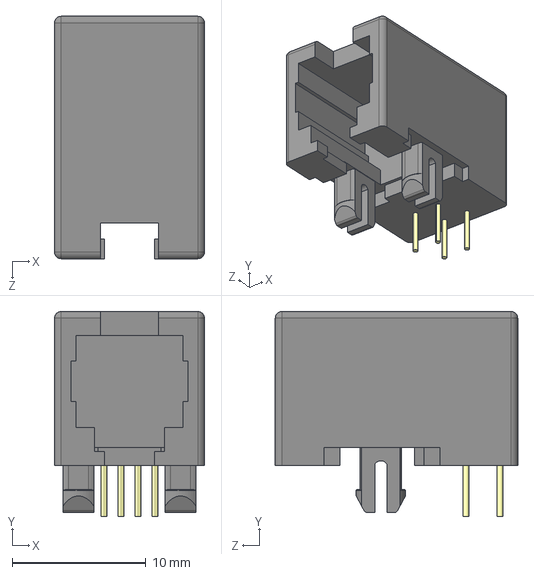
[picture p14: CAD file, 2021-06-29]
01_hardware/v0/3d_models/RJ10/955016449.stp
11.2 x 15.3 x 18.1 mm

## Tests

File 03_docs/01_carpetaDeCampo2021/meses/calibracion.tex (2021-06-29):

\section{Protocolo de calibración}

En esta sección daremos un paso a paso del proceso a seguir para poder comprobar la correcta calibración de un sensor de humedad de suelo.

\subsection{Elementos necesarios}

Para realizar la calibración necesitaremos:
\begin{itemize}
    \item Recipiente graduado o de volumen conocido: Debe ser lo suficientemente grande para almacenar la muestra de tierra deseada con el nivel de compactación y densidad requerida, teniendo espacio también para el sensor.
    También se recomienda que el recipiente sea relativamente rígido y permita un fácil acceso a la superficie del suelo a medir.
    Es muy importante poder saber el volumen del recipiente, ya que esto nos permite calcular el contenido volumétrico de agua.
    \item Recipientes para secado en horno.
    \item Tierra de características conocidas: Se recomienda no usar tierra con mucha composición orgánica, ya que la misma suele volatilizarse al hornearla, generando grandes errores de medición.
    \item Sensor de humedad a verificar: El proceso a realizar es válido para todos los sensores de tipo capacitivo, por lo que la calibración puede aplicarse a otros sensores que se usen en el mismo tipo de suelo.
    \item Balanza: Se necesita que tenga capacidad para pesar hasta 5 kilos y una resolución de al menos 1 gramo.
    \item Balanza de precisión: Se necesita que tenga  una resolución de al menos 0.1 gramo.
    \item Horno o dispositivo para secar la muestra: Cualquier horno capaz de mantener 105 o 110 \degree C sirve.
    \item Pulverizador a gatillo: Se empleará para una distribución uniforme de agua sobre la muestra.
    \item Sistema de adquisición de datos.
    \item Tutor para insertar sensor: Un dispositivo con punta, de diámetro similar al sensor, que se usará para clavar en la tierra y hacer espacio para la posterior instalación.
\end{itemize}

\begin{figure}[H]
    \centering
    
    \caption{Materiales utilizados.}
    \label{fig:materiales}
\end{figure}

\subsection{Procedimiento}

\subsubsection{Preparación de la muestra}

\begin{enumerate}

    \item Pesar el recipiente (limpio y seco) donde se almacenará la muestra.
    \item Debemos obtener la muestra a sensar. Para ello tenemos dos opciones, siendo la primera tomarla directamente del suelo a analizar, empleando un recipiente/sacabocados de volumen conocido; o bien colocando la tierra de propiedades conocidas en un recipiente y compactándola hasta alcanzar la densidad requerida.
    \item Tomar una sub muestra de 10 gramos usando una cuchara o herramienta similar y colocarlo en un recipiente para secado.
    \item Pesar la sub muestra + recipiente (de peso conocido) $M_{wet+recip_B}$ y taparla para evitar la perdida de humedad. Guardarla para su posterior secado.
    \item Anotar el peso ($M_{wet}$) y volumen ($V_{soil}$) de la muestra principal.
    \item Remover objetos grandes que puedan alterar las mediciones, como ser piedras, siempre y cuando no alteren la naturaleza de la muestra.
    \item En caso de ser suelos muy arcillosos o finos, tomar una medición de la altura que ocupa dentro del recipiente, ya que posteriormente su volumen puede cambiar al agregarle agua, por lo que sabiendo la altura se puede llegar a calcular una corrección.
    
\end{enumerate}

\begin{figure}[H]
    \centering
    
    \caption{Pesaje del recipiente.}
    \label{fig:pesaje_vaso}
\end{figure}

\subsubsection{Secado}

\begin{enumerate}

    \item Hornear la muestra principal a 110\degree C hasta lograr que esté completamente seca, variando el tiempo según el peso de muestra. Es recomendable esparcir la tierra en finas capas sobre una bandeja para lograr un secado mas rápido y uniforme.
    \item Sacar del horno y dejar enfriar por 2 horas.
    \item Pesar el suelo seco para obtener $M_{dry}$.
    \item Calcular la densidad aparente del suelo con la ecuación \ref{eqn:bulk_den}.
    
\end{enumerate}

\begin{figure}[h!]
    \centering
    
    \caption{Secado de tierra en horno.}
    \label{fig:secado}
\end{figure}
\newpage
\subsubsection{Calibración}

\begin{enumerate}

    \item Colocar la tierra seca en el contenedor para calibración, respetando la densidad y compactación necesaria. Para esto se recomienda ir depositando de a finas capas y compactándolas poco a poco.
    
    \item Introducir el sensor en la muestra, teniendo mucho cuidado de que no queden holguras con aire. Es muy importante que tenga un contacto pleno con la muestra para obtener mediciones acertadas. Se recomienda usar un tutor para hacer el hueco donde tiene que entrar el sensor. Este tiene que quedar completamente dentro de la tierra. Evitar colocarlo en un agujero usado por otro sensor anteriormente.
    \item Conectar el sensor al dispositivo de adquisición y anotar los valores RAW obtenidos.
    \item Retirar el sensor.
    \item Regar la tierra siguiendo una proporción de 1ml de agua por cada 10 ml de tierra, lo que aumentará en un 10\% el contenido de agua volumétrico ($V_{WC}$). Regar lo mas pareja posible la superficie.
    \item Cuidadosamente mezclar la tierra con una cuchara o herramienta similar hasta lograr una consistencia y humedad homogénea.
    \item Repetir los pasos de 2 a 6 hasta lograr la saturación de la tierra, proceso que puede llevar entre 4 y 6 lecturas, con una demora en la adquisición de una hora para cada una.
    \item Es importante destacar que la densidad y compactación de suelo debe mantenerse a lo largo de la prueba, logrando esto asegurándonos de que el volumen de la muestra se mantenga constante sin importar el contenido de agua agregada.
    
\end{enumerate}

\begin{figure}[H]
    \centering
    
    \caption{Recipiente con tierra a medir.}
    \label{fig:vaso_lleno}
\end{figure}

\begin{figure}[H]
    \centering
    
    \caption{Volumen de tierra a medir.}
    \label{fig:volumen}
\end{figure}

\begin{figure}[H]
    \centering
    
    \caption{Tutor para preparación de suelo.}
    \label{fig:tutor}
\end{figure}

\begin{figure}[H]
    \centering
    
    \caption{Hueco para la inserción del sensor.}
    \label{fig:hueco}
\end{figure}

\begin{figure}[H]
    \centering
    
    \caption{Captura de algunas mediciones tomadas.}
    \label{fig:mediciones}
\end{figure}

\subsubsection{Sub-muestra}

\begin{enumerate}

    \item Secar la sub-muestra de 10 gramos obtenida al principio, colocándola en el horno a 105 \degree C por 24 horas, duplicándose ese tiempo si se trata de tierra con alto componente orgánico, siendo necesario en esos casos usar una temperatura de 65 \degree C.
    \item Sacar del horno y dejar enfriar por 2 horas.
    \item Pesar el suelo seco para obtener $M_{dry+recip_B}$.

\end{enumerate}

\subsubsection{Cálculo y resultados}

\begin{enumerate}

    \item Todas las mediciones obtenidas, sean de peso, volumen o humedad y colocarlas en la tabla de excel para tal fin.
    \item Interpretar el gráfico de la recta de respuesta del sensor y compararlo con el del datasheet para verificar la correlación.
   
\end{enumerate}

\begin{figure}[H]
    \centering
    
    \caption{Planilla de excel usada para cálculos.}
    \label{fig:planilla}
\end{figure}

\begin{figure}[H]
    \centering
    
    \caption{Curva de respuesta del sensor.}
    \label{fig:respuesta}
\end{figure}

\subsection{Cálculos}

El contenido volumétrico del agua se define como el volumen de agua por volumen de suelo, donde $\theta$ representa el contenido volumétrico de agua, medido en $\frac{cm^3}{cm^3}$.

Otros conceptos que usaremos en este proceso son el volumen de agua, representado con $V_W$ y medido en $cm^3$, y volumen total, que en este caso hace referencia a la capacidad total del contenedor usado para tomar la muestra, representado por $V_T$ y medido en $cm^3$.

\begin{equation}
    \theta = \frac{V_w}{V_t}
    \label{eqn:cont_volum}
\end{equation}

Para calcular el volumen de agua, primero es necesario encontrar la cantidad inicial de agua en nuestra muestra, que se calcula restando el peso total del agua de la muestra, obtenida al multiplicar el peso de la muestra secada por el contenido gravimétrico de agua que se encontró a partir de la sub-muestra de la sección 3.2.4.

\begin{equation}
    m_{soil, sample} = m_{soil, sub-sample} - (m_{soil, sub-sample} \cdot w)
\end{equation}

Donde $m_{soil, sub-sample}$ es la masa de suelo con la que comenzamos y $w$ el contenido gravimétrico de agua calculado a partir de la sub-muestra.

\begin{equation}
    w = \frac{m_{soil, sub-sample}-m_{soil, sample}}{m_{soil, sample}}
\end{equation}

Luego, para encontrar $V_w$ para cada punto de calibración, hay que restar el peso del contenedor y el de $m_{soil, sample}$ del peso total de la muestra.

\begin{equation}
    m_w=m_{total}-m_{soil, sample}
\end{equation}

\begin{equation}
    V_w=\frac{m_w}{\rho_w}
\end{equation}

Dónde $m_w$ es la masa de agua, $m_total$ es la masa de suelo húmedo medida en gramos, $m_{soil, sample}$ es la masa de la muestra secada en horno y $\rho$ es la densidad de agua considerada como $\frac{1gr}{cm^3}$.

Si usamos $V_t$, podemos calcular el contenido volumétrico de agua y la densidad aparente del suelo mediante la ecuación \ref{eqn:cont_volum}, estando esta última definida como la densidad de suelo seco, representada como $\rho_b$ y medida en $\frac{g}{cm^3}$.

\begin{equation}
    \rho_b = \frac{m_{dry}}{V_{soil}}
    \label{eqn:bulk_den}
\end{equation}

Todo lo anterior, en conjunto con la tabla de excel que se encuentra adjunta, permiten realizar la verificación de calibración de nuestro sensor, siendo esto apreciable en el gráfico presente en esta última, el cual usa la herramienta de tendencia para interconectar las mediciones obtenidas y obtener la respuesta de nuestro sensor, la cual puede ser lineal, variando en casos donde la tierra presente un alto contenido de materia orgánica.

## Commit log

2021-06-29 Actualizacion 29/06/21
    Actualizo carpeta de campo.
    [tesis_hw.kicad_pcb, tesis_hw.sch]
2021-06-29 [PCB] Primer bosquejo de placa(V0).
    Organizo directorio de V0
    Busco ESP, RJ10, TCA y PCF
    [955016449.stp, rpi_MECH_3bplus.dxf, tesis_hw.kicad_pcb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]
2021-11-21 Agrego repos de HW y FW.
    * Agrego repo de hw con version 1.0
    * Agrego repo de fw con version 0.1
    [configuration.h]
